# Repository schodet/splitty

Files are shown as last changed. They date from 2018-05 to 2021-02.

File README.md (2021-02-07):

Splitty
=======

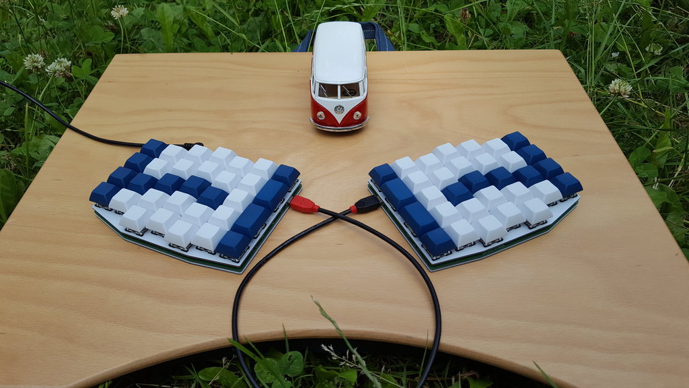
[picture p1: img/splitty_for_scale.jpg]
Splitty


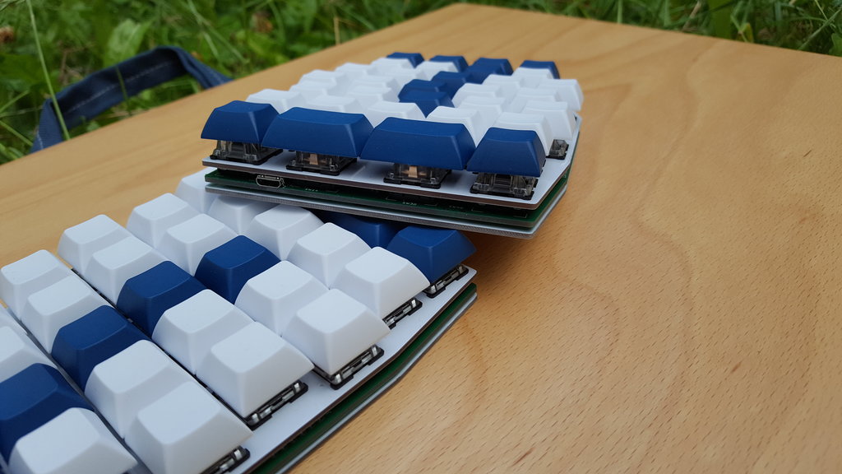
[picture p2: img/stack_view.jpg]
Splitty Stack


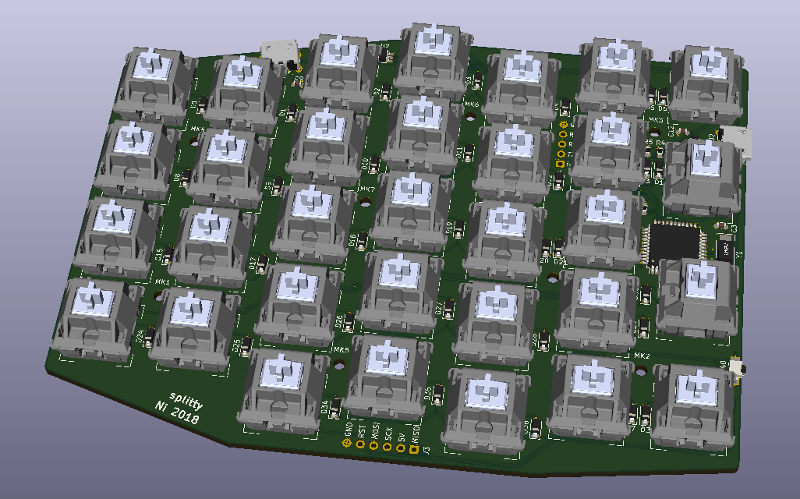
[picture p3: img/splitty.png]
Splitty PCB


[More pictures](gallery.md)

This is a split ergonomic keyboard based on the Ergodox layout without the
thumb cluster. It uses 32 keys per sides with Cherry MX compatibles switches,
thirty 1u and two vertical 1.5u caps.

The controller is integrated in order to make the keyboard as slim as
possible.

It connects to the computer using a micro-B USB. Both sides are connected
together also using micro-B USB. Any connection mistake should not break
anything and the keyboard supports hot plugging.

BOM
---

All prices in euro.

Here is what is needed for one half, with references at Farnell and LCSC for
some parts.

| Quantity | Designator | Description | Farnell | Price | Total | LCSC | Price  | Total |
| ---: | --- | --- | ---: | ----: | ----: | ---: | -----: | ----: |
| 32 | SW0-38 | Cherry MX switches | | | | | | |
| 3 | C1, C11, C12 | Capacitor 0603 1μF >6V X7R | 2346895 | 0.055 | 0.165 |  C93816 | 0.0172 | 0.052 |
| 2 | C3, C4 | Capacitor 0603 22pF >6V C0G/NP0 | xxxxxxx | xxxxx | xxxxx | C106245 | 0.0084 | 0.017 |
| 6 | C5-10 | Capacitor 0603 100nF >6V X7R | 2320803 | 0.037 | 0.222 | C187860 | 0.0231 | 0.139 |
| 32 | D0-38 | Diode SOD-123 | 2760402 | 0.079 | 2.528 |  C83528 | 0.0091 | 0.291 |
| 2 | J1,J2 | Connector USB Micro-B Würth 629105150521 | 2470822 | 1.360 | 2.720 | | | |
| 2 | R1, R2 | Resistor 0603 22Ω | 9331891 | 0.002 | 0.004 | | | |
| 3 | R3, R4, R5 | Resistor 0603 10kΩ | xxxxxxx | xxxxx | xxxxx | | | |
| 1 | SW40 | Tactile Switches Omron B3U-3000P-B | 1333656 | 0.420 | 0.420 | | | |
| 1 | U1 | ATmega32U4-AU | 2443182 | 3.570 | 3.570 |  C44854 | 3.1513 | 3.151 |
| 2 | U2, U3 | ST USBLC6-2SC6 | 1269406 | 0.313 | 0.626 | C7519 | 0.1456 | 0.291 |
| 1 | Y1 | Crystal Abracon ABM3 16MHz | 1611806 | 0.660 | 0.660 | | | |
| 8 | | M2 screw, 6mm | 1420386 | 0.012 | 0.094 | | | |
| 16 | | M2 nuts | 1419445 | 0.009 | 0.150 | | | |
| | | | | Total | 11.19 | | | |
| | | | | x2 | 22.38 | | | |

Boards were ordered at JLCPCB, you can ask for delivery of JLCPCB and LCSC
orders in the same package.

| Description | JLCPCB by | Price | Unit  | JLCPCB by | Price | Unit  |
| --- | --- | ----- | ----- | --- | ----- | ----- |
| Printed Circuit Board (green) | 5 | 11.25 | 2.250 | 10 | 15.20 | 1.520 |
| Front Plate (white) | 5 | 18.55 | 3.710 | 10 | 22.49 | 2.249 |
| Back Plate (white) | 5 | 18.55 | 3.710 | 10 | 22.49 | 2.249 |

My actual orders
----------------

Cool Jazz (AliExpress):

 - 92 Gateron MX brown switches: 21.93 €
 - Ergodox PBT blank keycaps (60 1u, 16 1.5u, 4 2u): 23.12 €
 - Total: 45.05 €

Farnell:

 - 4 connector USB: 5.44 €
 - 2 quartz: 1.32 €
 - 100 screws: 1.17 €
 - 100 nuts: 0.94 €
 - Shipping: 6.90 €
 - Taxes: 3.16 €
 - Total: 18.93 €

JLCPCB + LCSC:

 - 5 PCB: 11.25 €
 - 5 Front Plate: 18.55 €
 - 5 Back Plate: 18.55 €
 - Shipping (JLCPCB, DHL): 5.03 €
 - 10 ST USBLC6: 0.72 €
 - 4 ATmega32U4: 12.59 €
 - 140 diodes: 1.27 €
 - 50 1uF capacitors: 0.86 €
 - Shipping (LCSC): 0.17 €
 - Taxes + DHL tip(!): 27 €
 - Total: 95.99 €

Personal stock:
 - Some resistors and capacitors.

I have enough components for two keyboards except USB connectors, quartz
(forgotten in Farnell order), switches and caps (they will probably be
different), and an extra set of boards.

Grand total: 159.97 €

Grand total (for one keyboard): 111.98 €

Slim stack
----------

A special attachment is used to make sure the stack is as slim as possible:

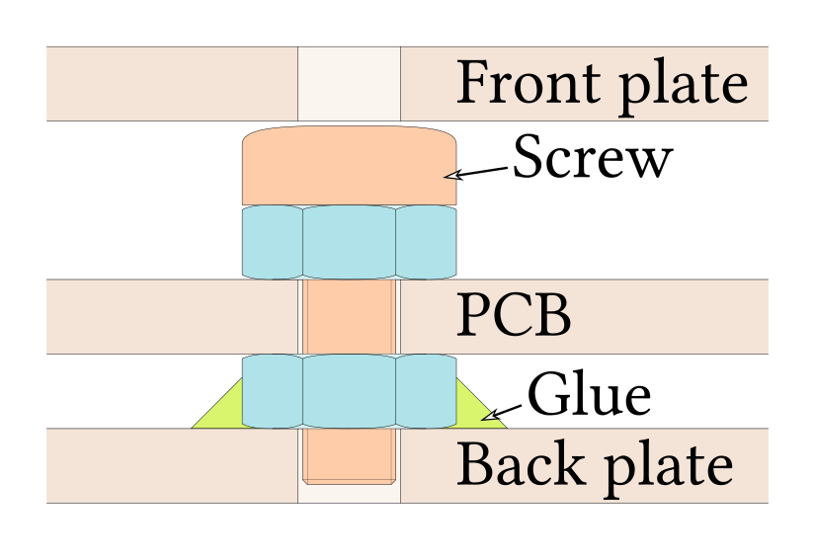
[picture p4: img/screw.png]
Screw attachment


Assembly and more
-----------------

See the [build log](build.md) and the [FAQ](faq.md).

License
-------

Copyright (C) 2018 Nicolas Schodet

Permission is hereby granted, free of charge, to any person obtaining a copy
of this software and associated documentation files (the "Software"), to deal
in the Software without restriction, including without limitation the rights
to use, copy, modify, merge, publish, distribute, sublicense, and/or sell
copies of the Software, and to permit persons to whom the Software is
furnished to do so, subject to the following conditions:

The above copyright notice and this permission notice shall be included in all
copies or substantial portions of the Software.

THE SOFTWARE IS PROVIDED "AS IS", WITHOUT WARRANTY OF ANY KIND, EXPRESS OR
IMPLIED, INCLUDING BUT NOT LIMITED TO THE WARRANTIES OF MERCHANTABILITY,
FITNESS FOR A PARTICULAR PURPOSE AND NONINFRINGEMENT. IN NO EVENT SHALL THE
AUTHORS OR COPYRIGHT HOLDERS BE LIABLE FOR ANY CLAIM, DAMAGES OR OTHER
LIABILITY, WHETHER IN AN ACTION OF CONTRACT, TORT OR OTHERWISE, ARISING FROM,
OUT OF OR IN CONNECTION WITH THE SOFTWARE OR THE USE OR OTHER DEALINGS IN THE
SOFTWARE.

The splitty symbol and footprint libraries use the same license.

Artwork on the back plate was made from "Van Volkswagen Vintage Old Car
Transporter Vw" under Creative Commons Zero - CC0.

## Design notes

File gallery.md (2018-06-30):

Splitty gallery
===============

Splitty for scale

Stack view

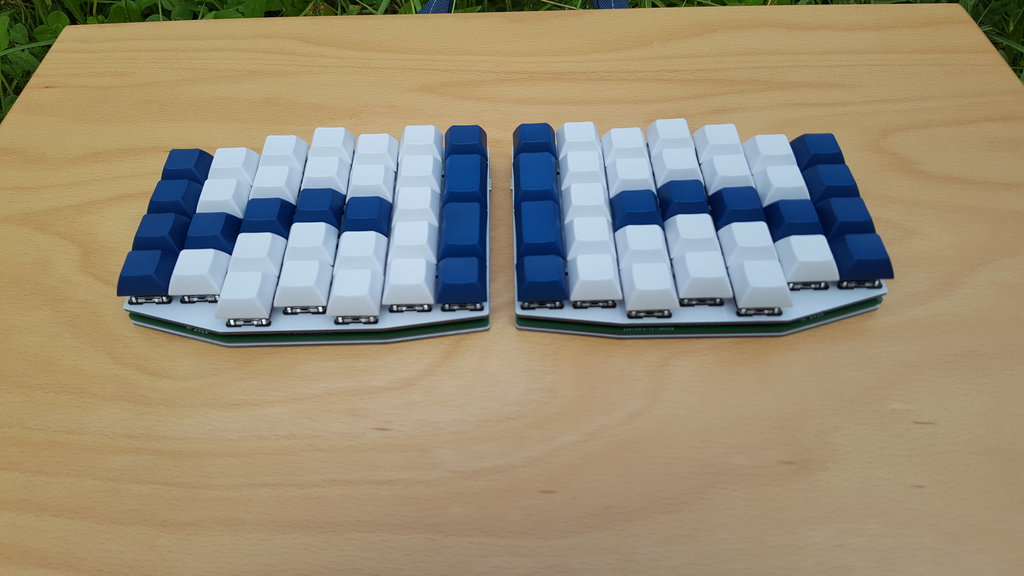
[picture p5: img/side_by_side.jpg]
Side by side


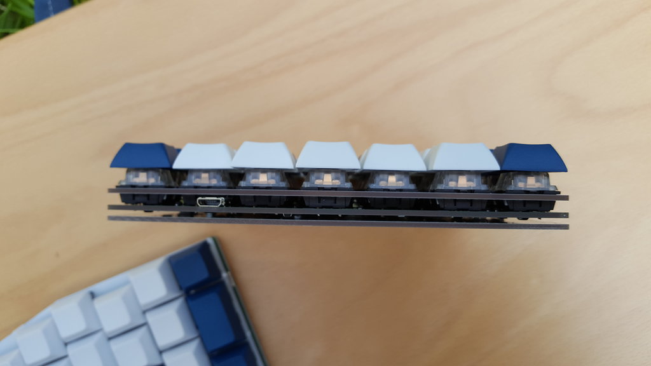
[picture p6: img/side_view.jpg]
Side view


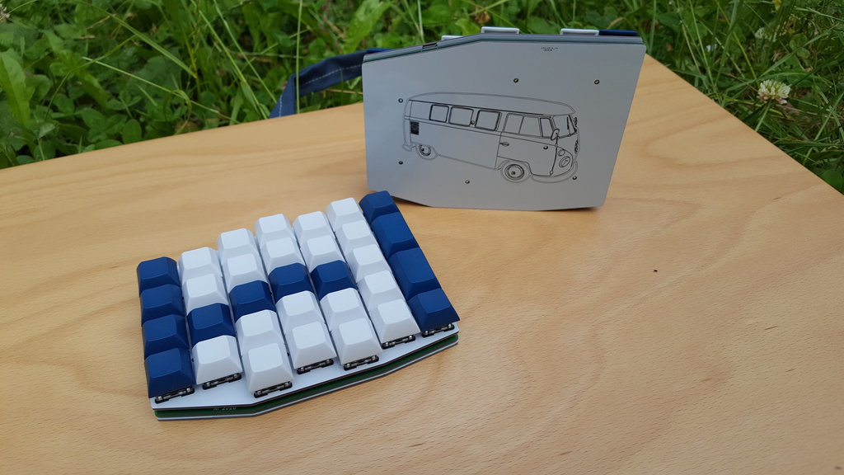
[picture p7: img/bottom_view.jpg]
Bottom view


PCB render

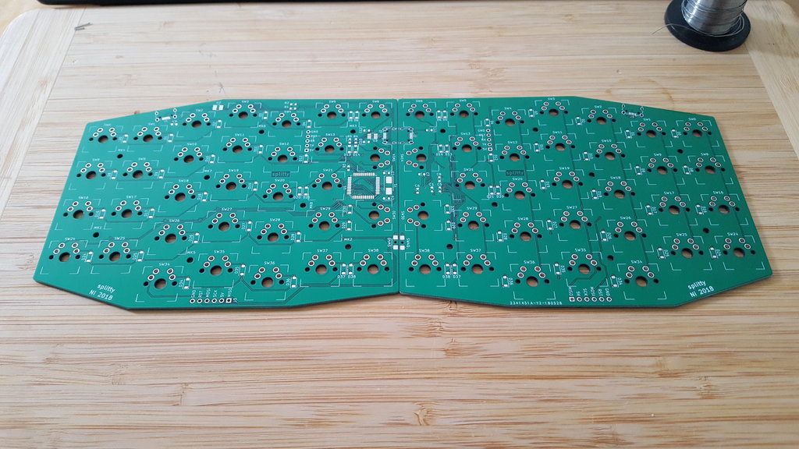
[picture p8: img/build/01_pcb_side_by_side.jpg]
PCB side by side


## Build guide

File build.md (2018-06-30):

Build log
=========

Here are my tools used to solder the splitty:

- a simple soldering iron (with a quite large tip),
- solder (make sure the iron temperature matches the solder),
- a metallic sponge,
- solder wick (for fast SMD soldering),
- tweezers.

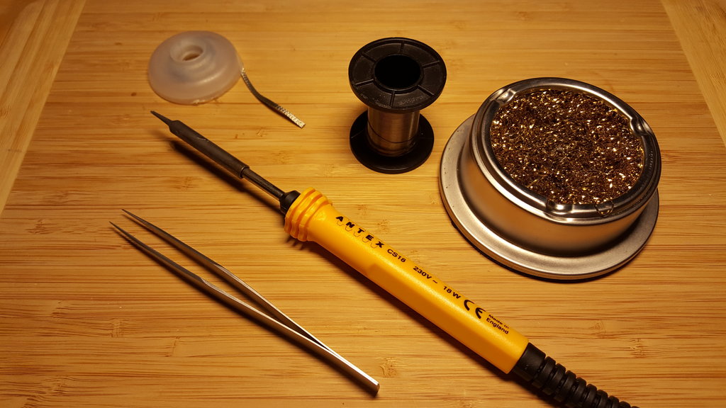
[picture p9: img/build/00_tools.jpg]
Tools


Also not shown on the picture:

- a small screwdriver,
- a 4 mm wrench or pliers,
- a flush cutter,
- a conductivity tester,
- a magnifier,
- glue (cyanoacrylate).

OK, let’s start.

The PCB is the same for both halves, one will have components on top and the
other on the bottom face.

Some components can be soldered on any face:

- the switches of course,
- diodes can be soldered on any face, choose your side,
- connectors and reset switch are supposed to be soldered on the top face,
- only one of C11 or C12 need to be soldered, choose one.

Lay down PCBs side by side to avoid silly mistakes:

PCB side by side

First components to solder are the diodes, check the polarity, the thin line
on the component corresponds to the cathode and must be oriented on the side
with the longer line on the silkscreen.

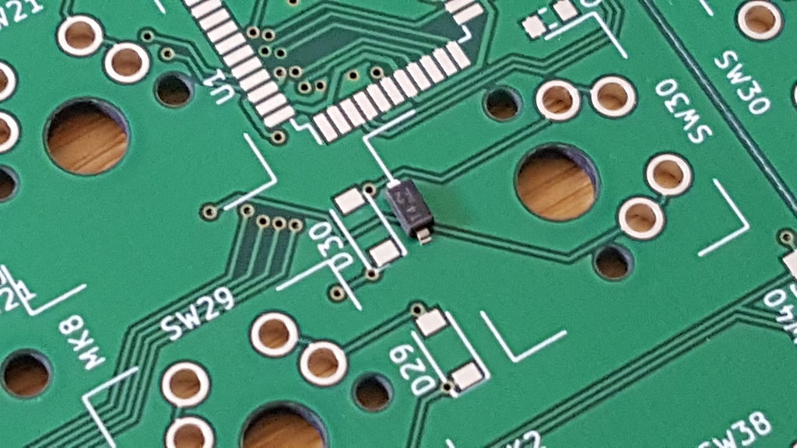
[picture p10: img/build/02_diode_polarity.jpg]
Diode polarity


The technique to solder small components is always the same, apply some solder
on one pad on the PCB, then press the component against the board and heat its
leg and your solder pad. The component will sink into the solder. Then, apply
solder to the other side while heating both the pad and the leg.

If one side is connected to a copper plane, choose this pad as the first one.
If you don’t, there is a risk that the first pad solder will melt while you
try to heat the pad connected to the plane.

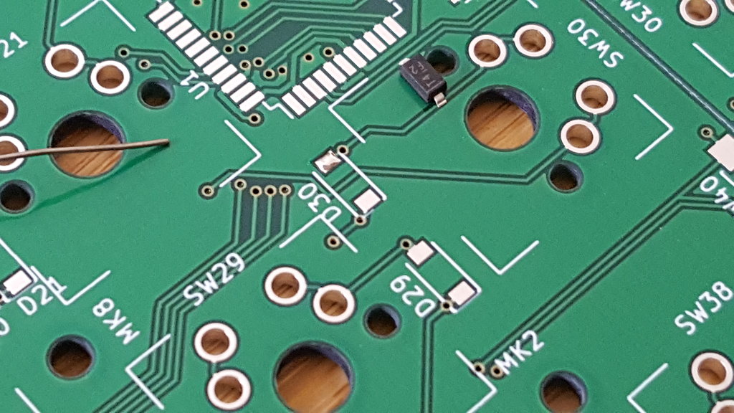
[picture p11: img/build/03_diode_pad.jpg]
Put solder on the first pad

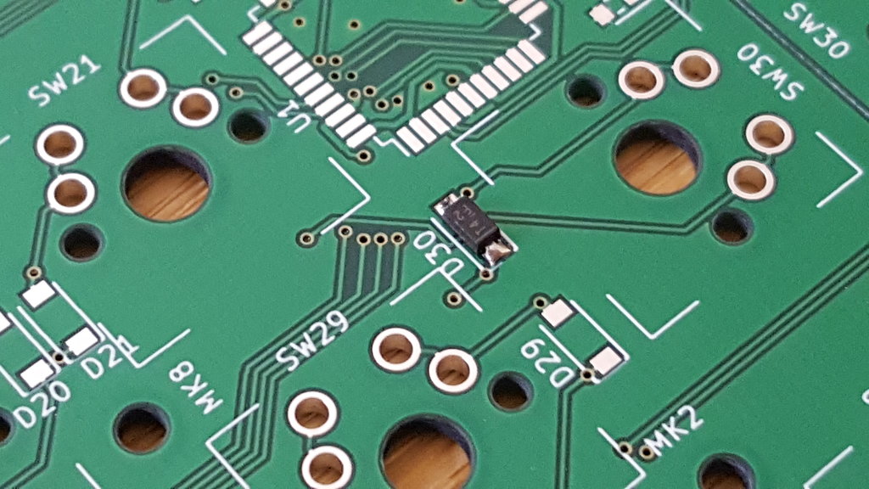
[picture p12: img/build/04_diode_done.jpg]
Soldered diode


Next component to solder is the micro USB socket as this is the trickiest part
to solder.

Start with the same technique used for the diodes. Apply solder on one pad,
choose the pad connected to the ground plane. Push the connector into place
while heating its leg and the pad and check the alignment is correct.

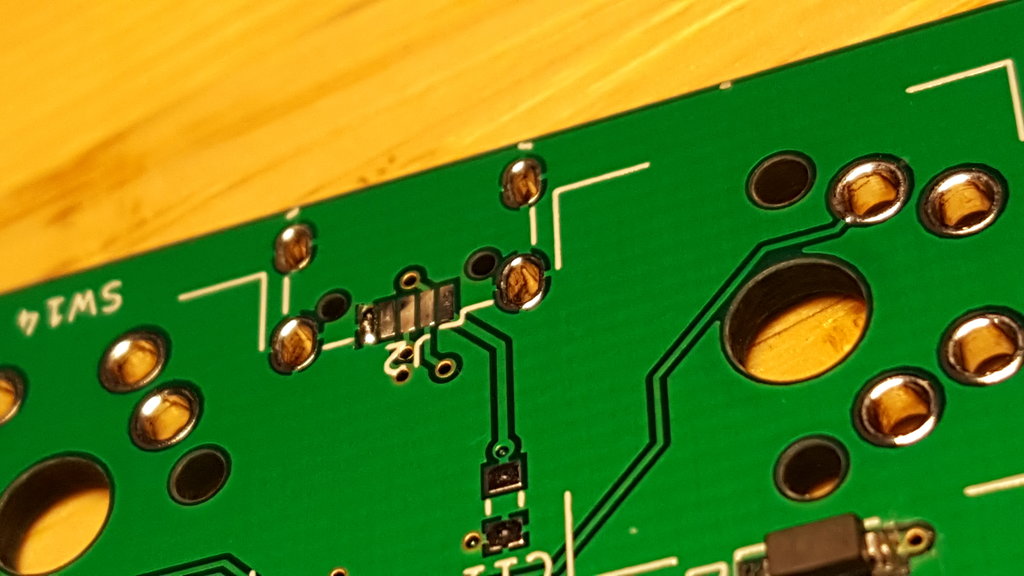
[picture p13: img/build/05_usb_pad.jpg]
The first USB pad


Then I use a surprising technique which works really well for components with
small pitch: apply solder to all pads and legs, with proper heating to both
the pads and the legs as always. All the pads… as the same time… there will be
shorts.

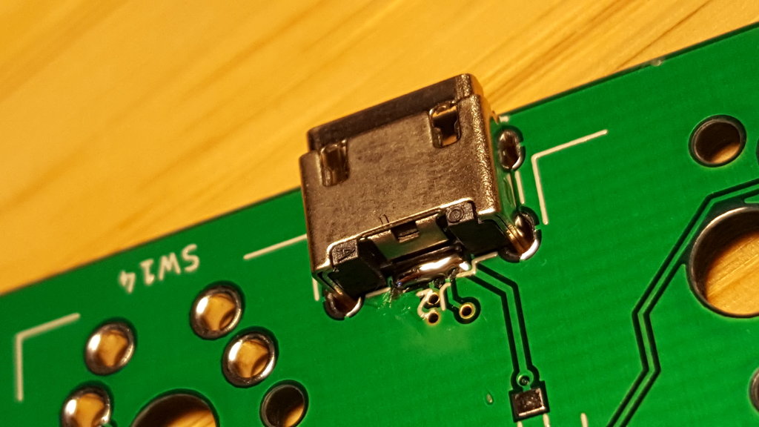
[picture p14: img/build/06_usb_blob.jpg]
Do not fear the solder blob


Now, put the solder wick above the contacts, apply a little drop of solder on
the tip of your iron to improve heat transfer, then press it firmly against
the wick for two seconds. Most solder will be sucked by the solder wick and
only a sufficient amount on solder will stay, removing any shorts while still
ensuring a good contact.

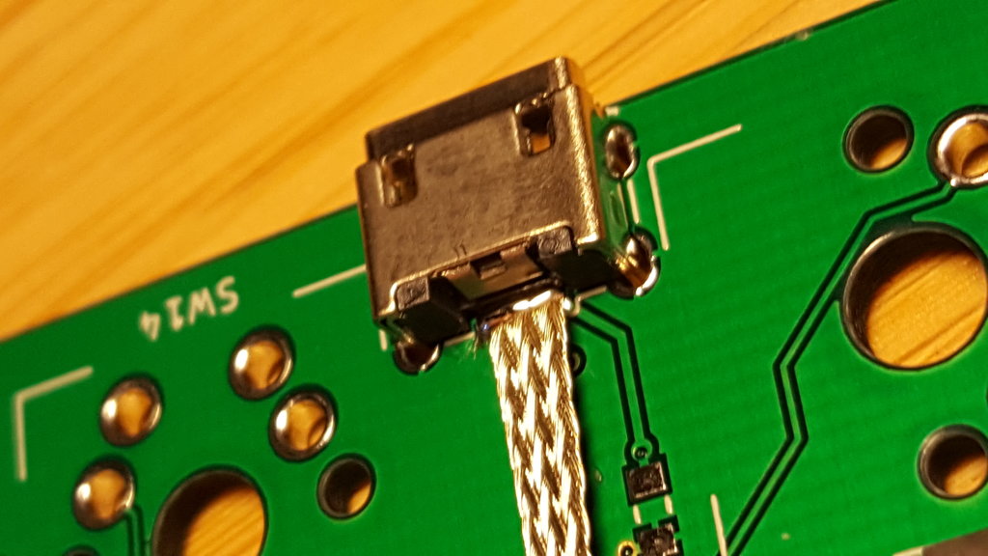
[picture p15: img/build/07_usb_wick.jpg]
This technique really sucks!


Now solder the large legs to ensure good mechanical support.

Test your connections, this is easy with this kind of cable, you can even
apply some force on the connector and see if the connection is rock solid:

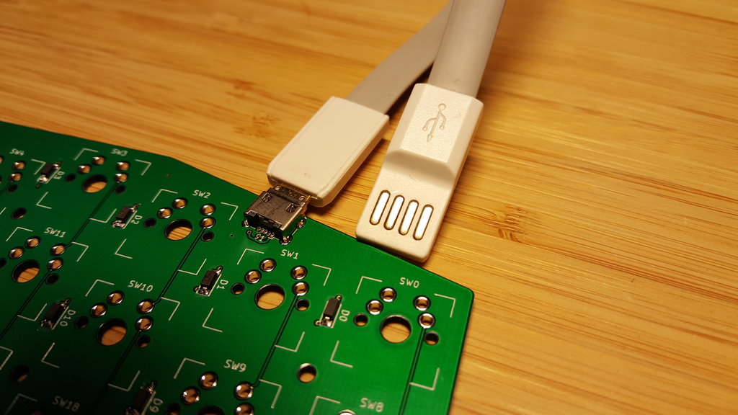
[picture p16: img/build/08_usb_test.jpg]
Nude USB contacts


Soldering the rest of the components is a piece of cake, but keep things
organized:

(TODO: make a video of how easy it is to solder a ATMEGA32u4).

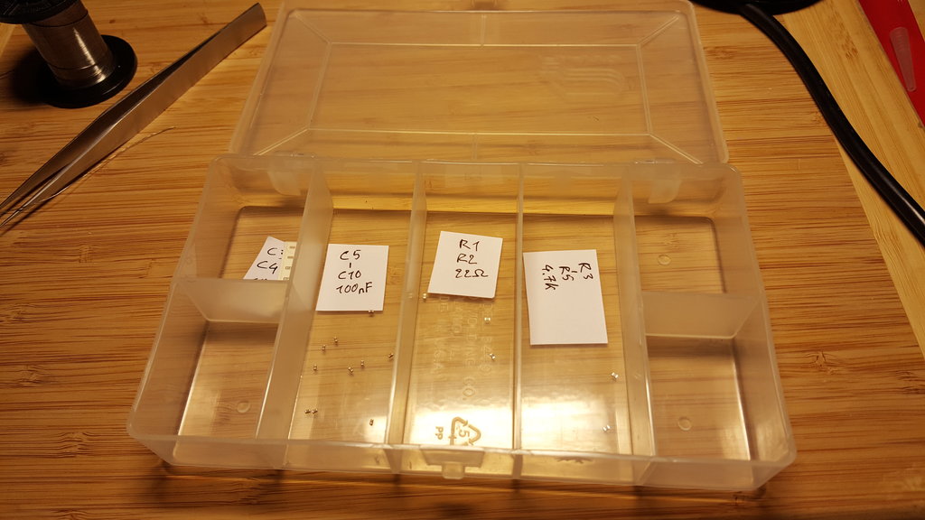
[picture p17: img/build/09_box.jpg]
When the box is empty, you’re done


The splitty does not use spacers, and you need to prepare screws now before
the front plate is attached.

Here is a schematic of the attachment:

Screw attachment

Before the switches and therefore the front plate are mounted, you need to
install the screws and the first nuts. A nut is temporary used on the other
side so that the screw does not fall during the preparation.

Now it is time to test *every* connections. Repairing a connection (especially
on the left hand half) will be much harder once the front plate is installed!

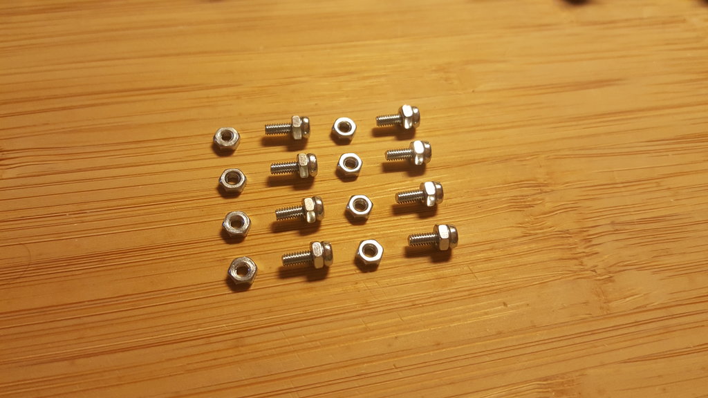
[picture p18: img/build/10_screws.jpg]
The height screws and their companions


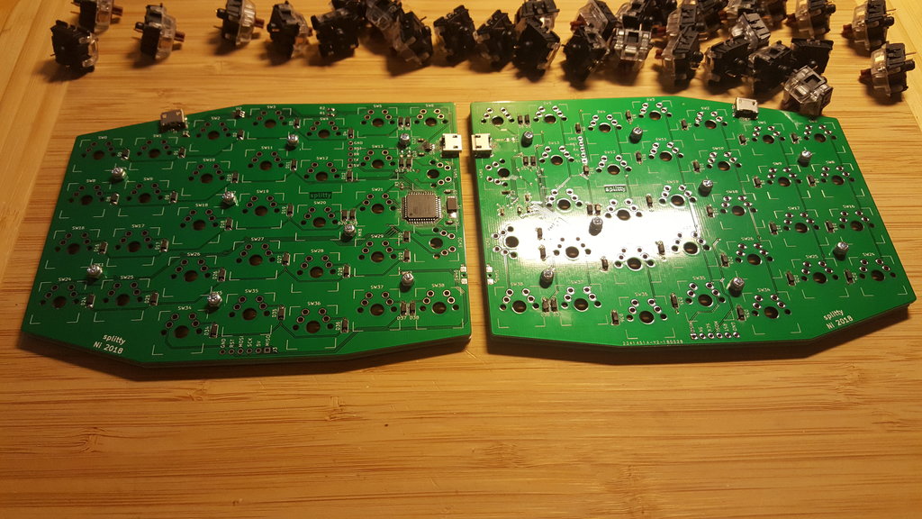
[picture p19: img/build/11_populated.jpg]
Ready to mount the switches


First start with the corner switches so that the front plate is leveled.

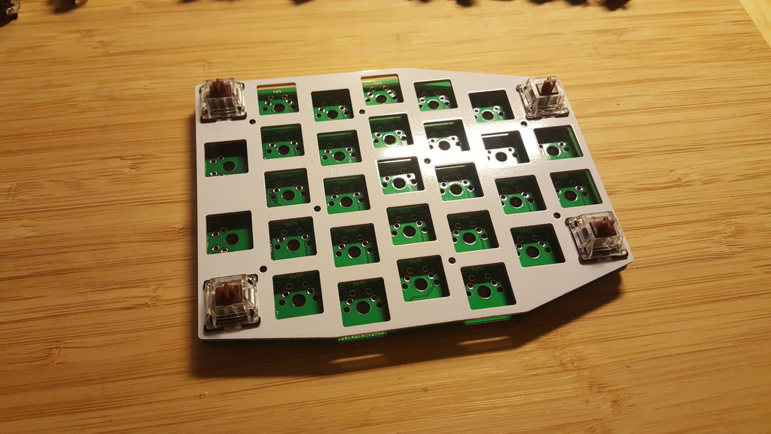
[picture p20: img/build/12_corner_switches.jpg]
Corner switches


Then proceed with the other switches.

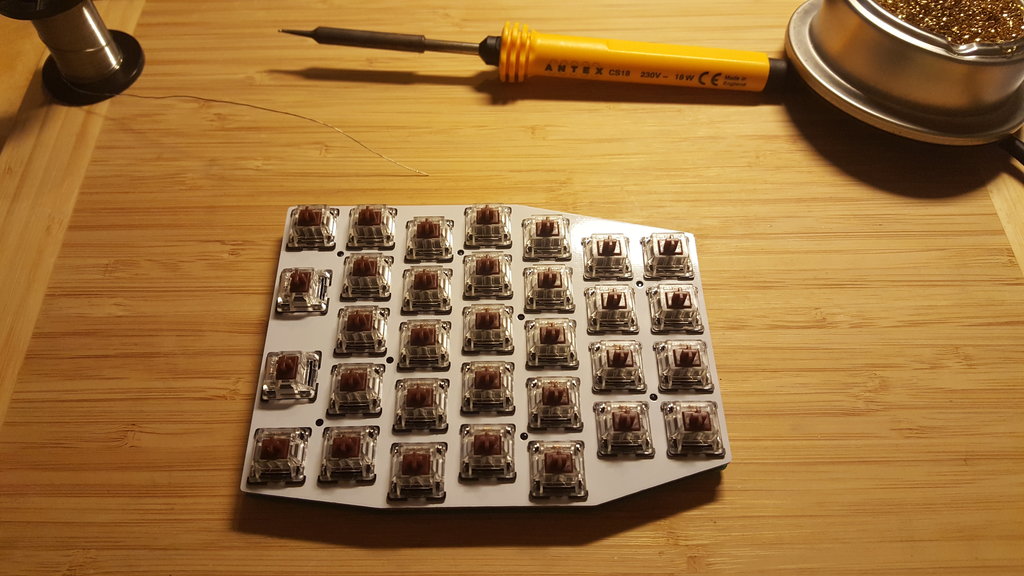
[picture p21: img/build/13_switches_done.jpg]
Now this really looks like a keyboard!


I started with the right side so a mistake can be fix more easily.

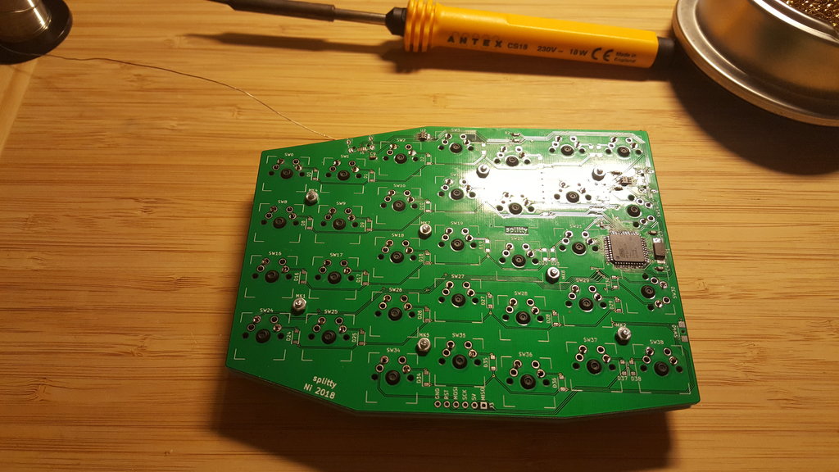
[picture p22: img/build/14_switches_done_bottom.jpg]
Under the switches


To glue the nuts to the bottom plate, use a screw to hold the nut in place.

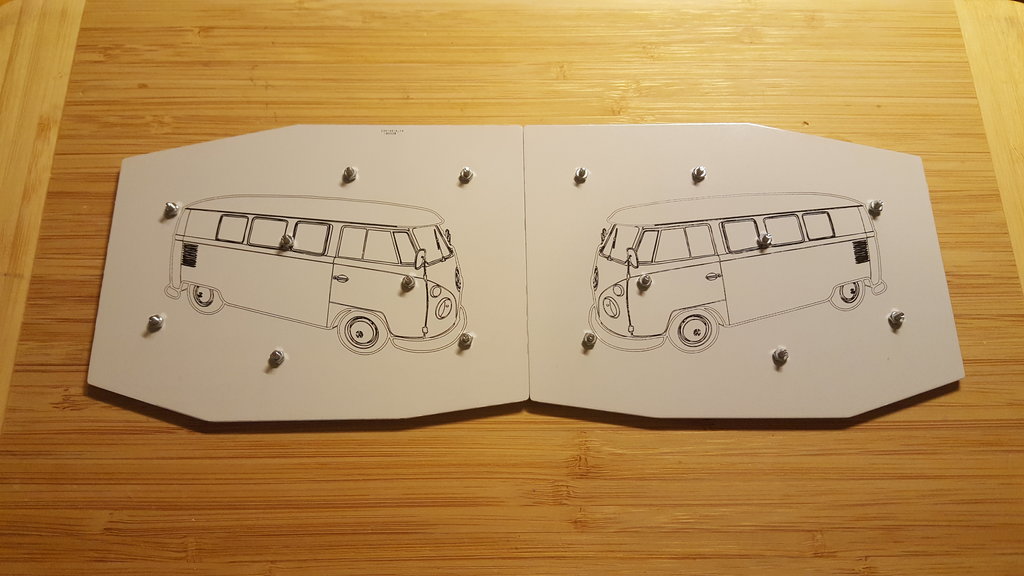
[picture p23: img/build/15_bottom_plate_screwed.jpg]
Bottom plate screwed


Apply glue around every nuts and remove the screw before the glue has
completely dried.

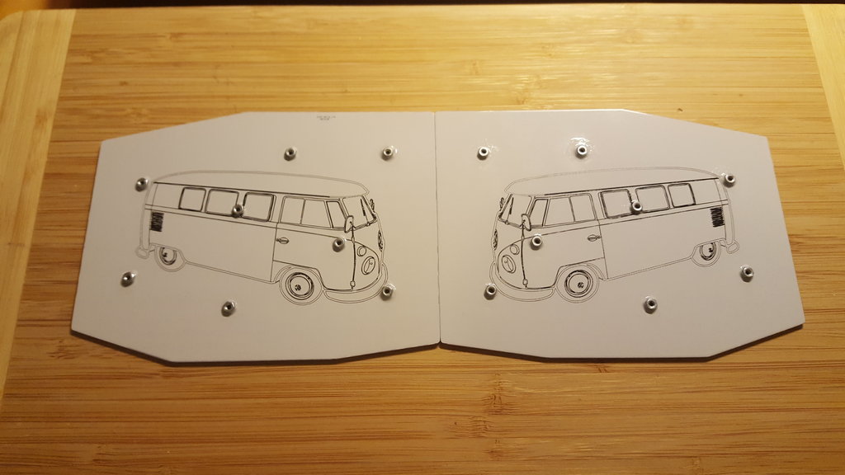
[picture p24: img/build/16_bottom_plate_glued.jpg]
Same thing, but without the screws


Depending on your switches and nuts, you may need to cut a little bit of the
switches legs. Another solution is to add enough washers so that is not
needed.

For the final assembly, you can not screw every screw one after the other, you
need to turn one turn on every screws, then repeat until every screws are
tighten.

Well done:

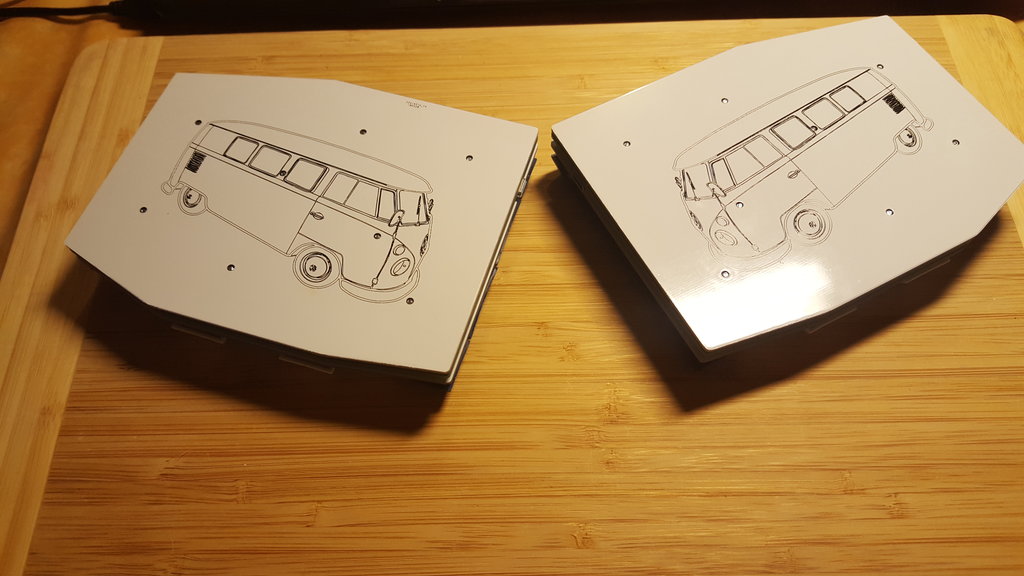
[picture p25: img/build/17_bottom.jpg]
Bottom


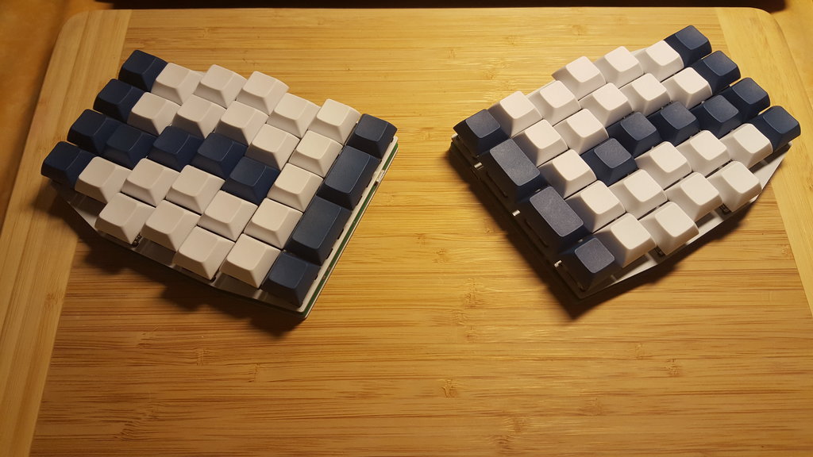
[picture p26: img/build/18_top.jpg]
Top


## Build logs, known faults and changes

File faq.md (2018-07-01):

FAQ
===

Why is the inner index column staggered up?
-------------------------------------------

Because I find it more comfortable to extend the index to the side and up
rather than straight to the side.

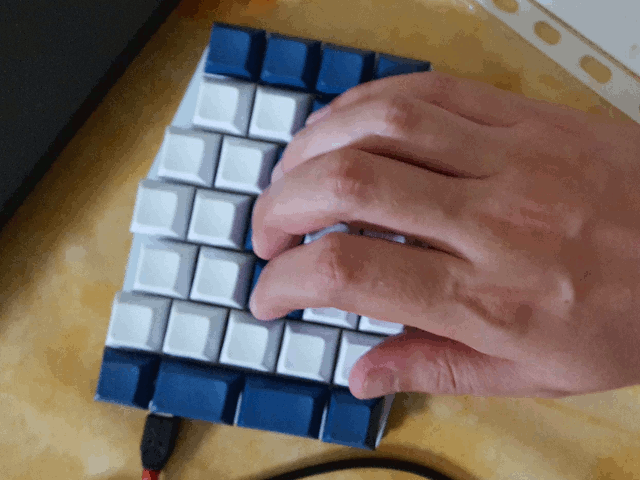
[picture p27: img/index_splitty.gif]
The splitty way


A right hand on a left splitty half to simulate the other stagger:

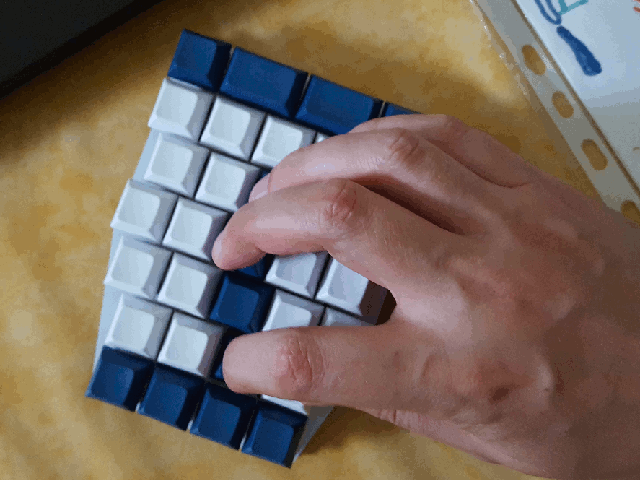
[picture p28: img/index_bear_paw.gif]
The other way


I am not alone, the same arrangement is used on the [mitosis][] for example.

It is also the case of a strange keyboard that a lot of people uses, as the
arm come from the side, the inner row is actually shifted up:

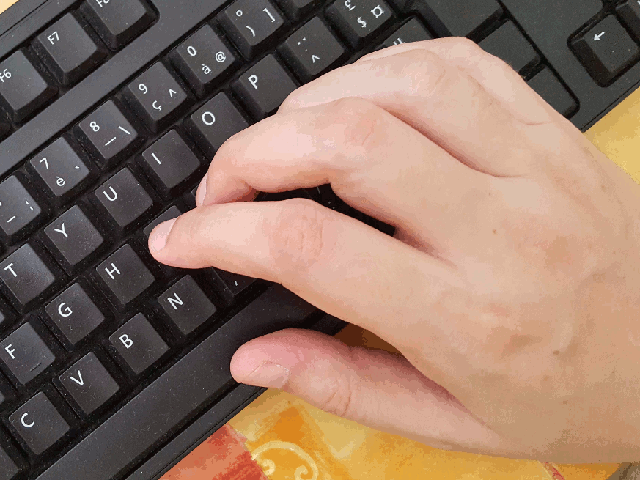
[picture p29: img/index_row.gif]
The strange row staggered keyboard


[mitosys]: https://www.reddit.com/r/MechanicalKeyboards/comments/66588f/wireless_split_qmk_mitosis/

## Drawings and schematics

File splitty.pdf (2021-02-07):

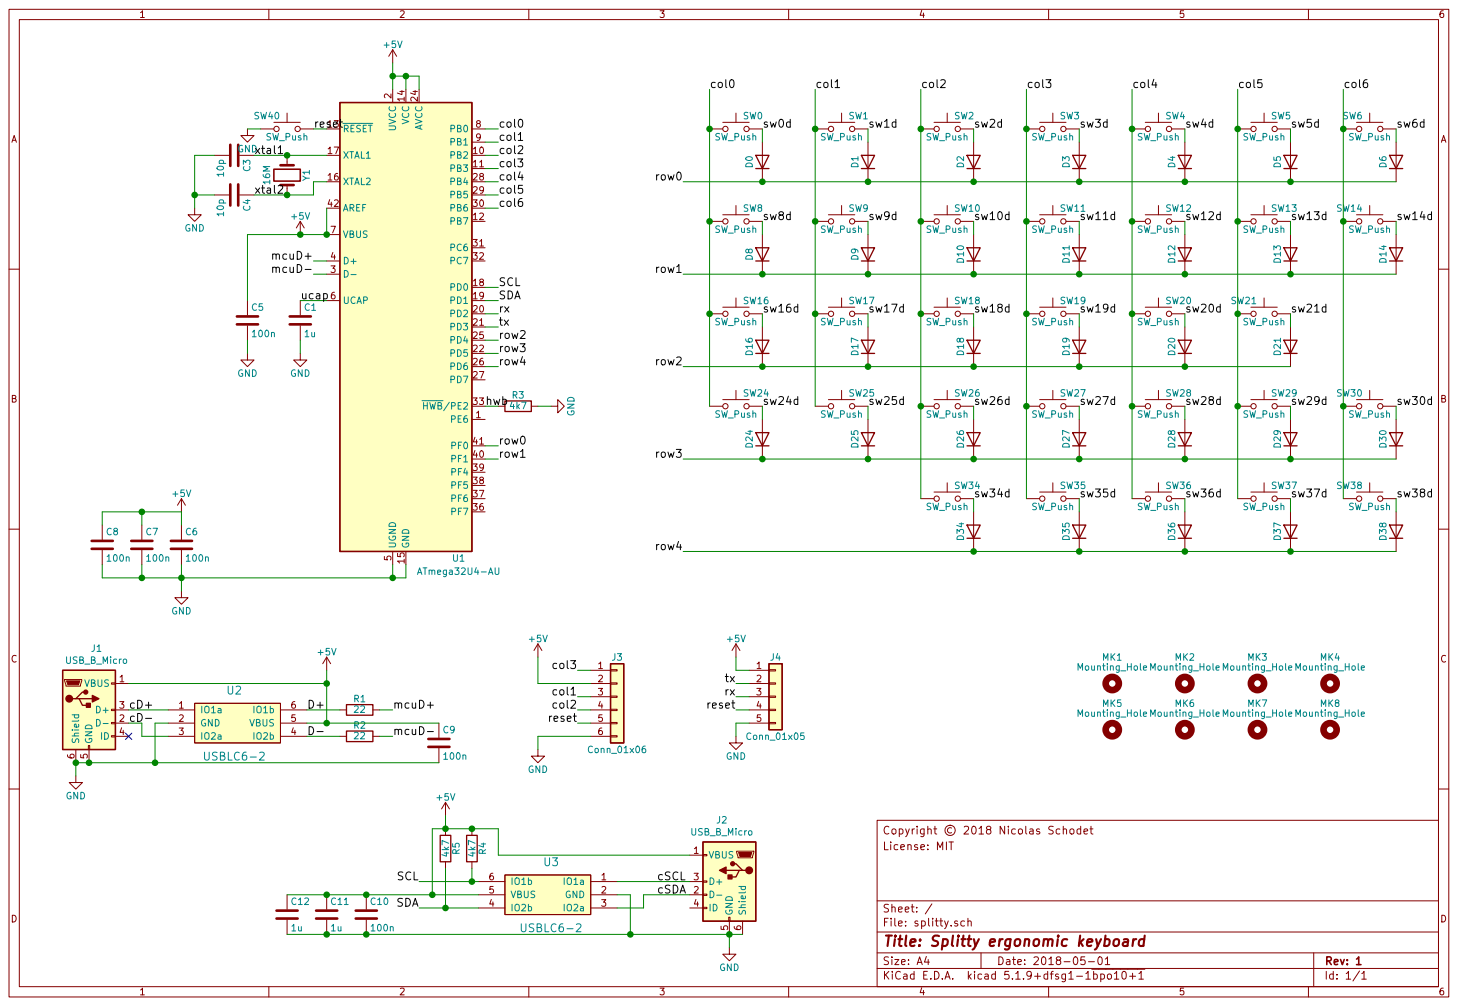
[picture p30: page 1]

2 PD2 20 PD3 21 PD5 22 AVCC 24 PD4 25 PD6 26 PD7 27 PB4 28 PB5 29 D- 3 PB6 30 PC6 31 PC7 32 HWB/PE2 33 PF7 36 PF6 37 PF5 38 PF4 39 D+ 4 PF1 40 PF0 41 AREF 42 UGND

5 UCAP 6 VBUS 7 PB0 8 PB1 9 U1 ATmega32U4-AU GND

SW8 SW_PushD8 SW16 SW_PushD16 SW24 SW_Push | SW2 SW_Push | SW12 SW_Push SW1 SW_PushD1 SW9 SW_PushD9 SW17 SW_PushD17 SW25 SW_PushD25

sw17d SCL

File: splitty.sch Sheet: / License: MIT Copyright © 2018 Nicolas Schodet

Id: 1/1 Title: Splitty ergonomic keyboard

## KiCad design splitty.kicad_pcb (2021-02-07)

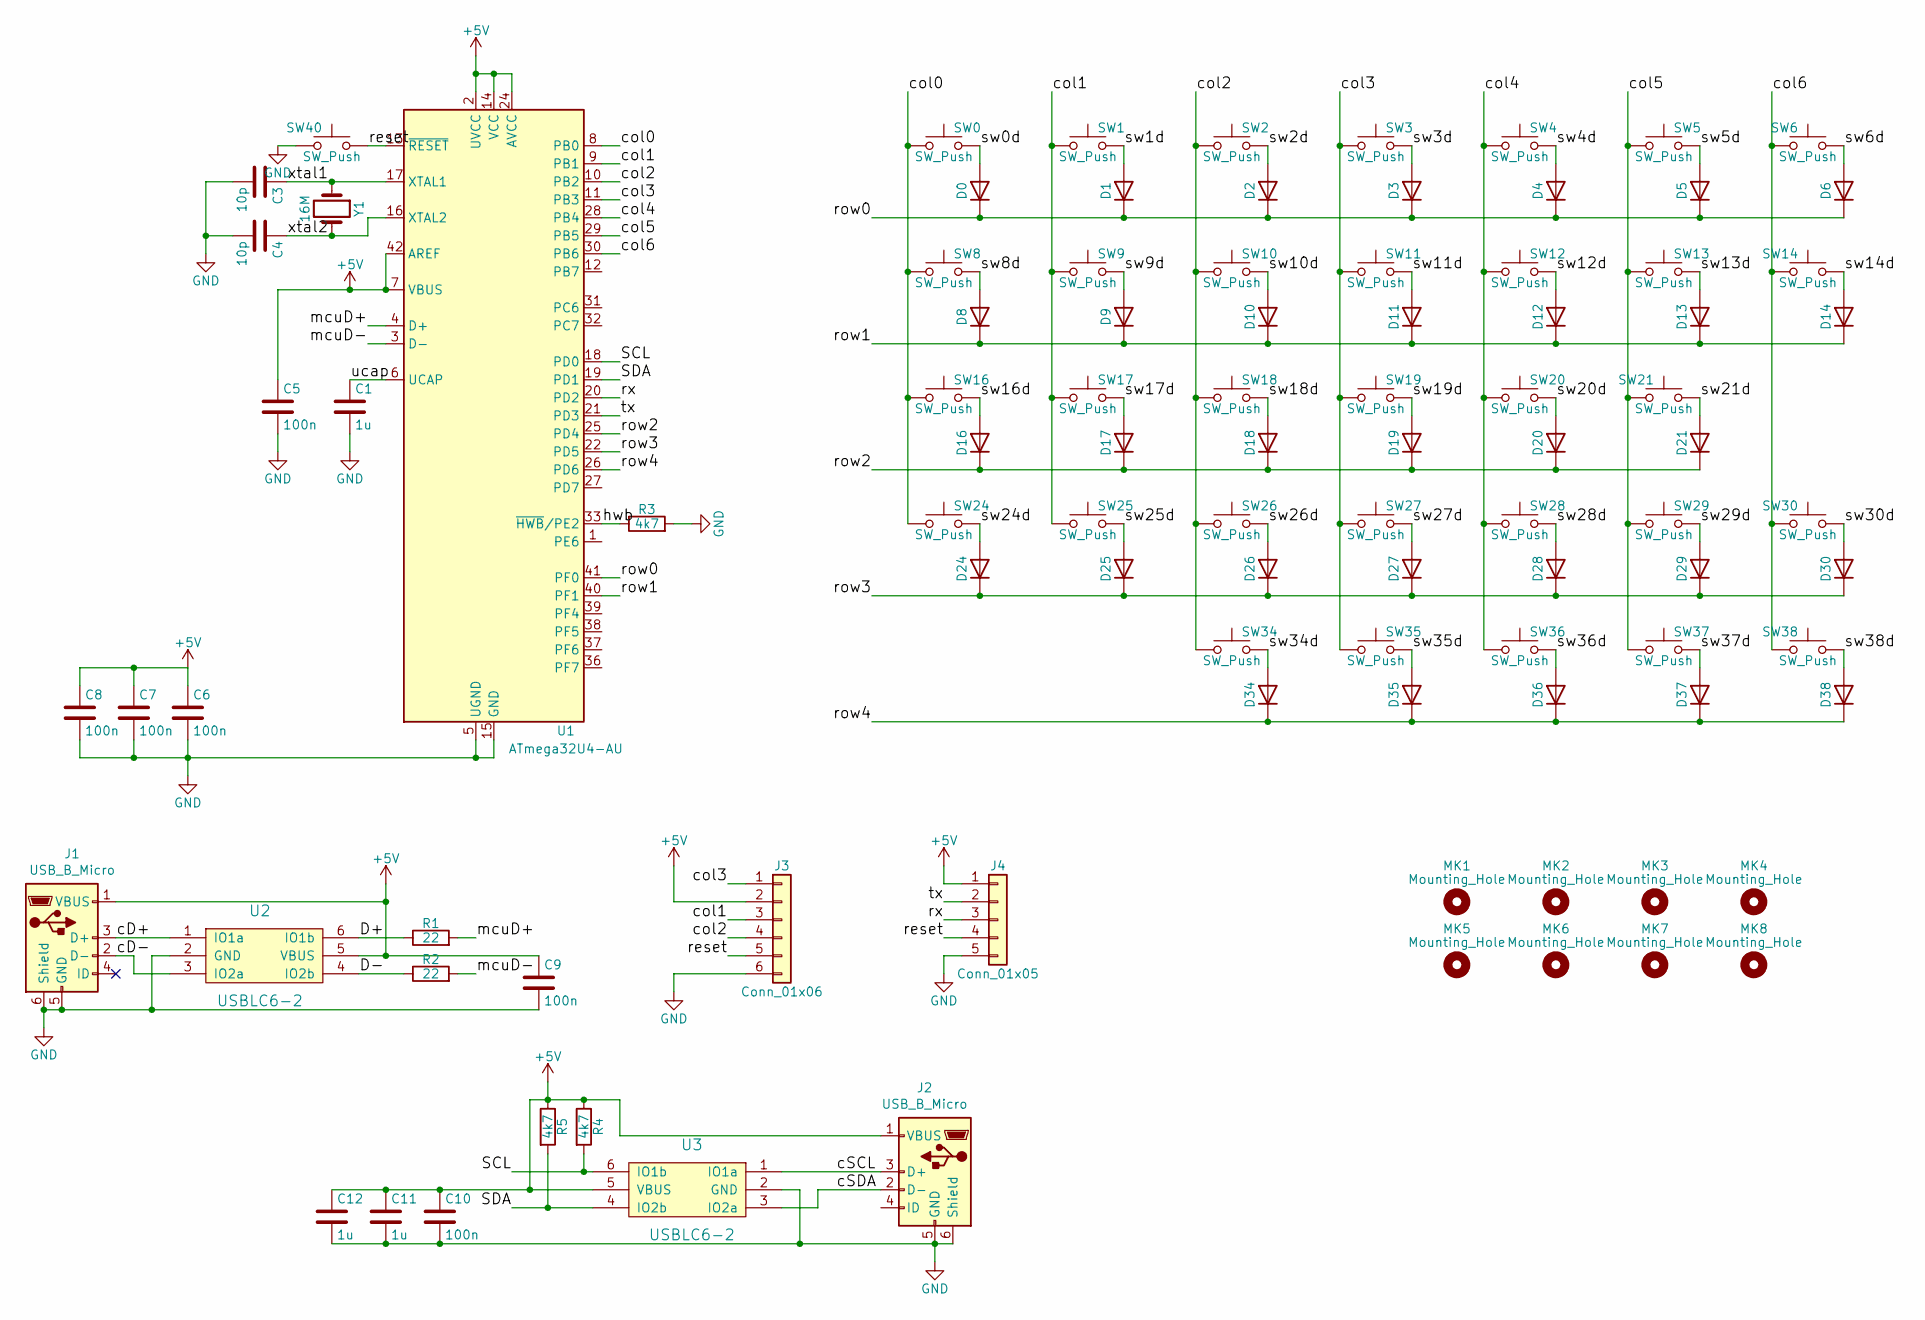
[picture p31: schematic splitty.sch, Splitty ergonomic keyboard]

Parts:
C1, C11, C12: 1u; C_0603_1608Metric_Pad1.05x0.95mm_HandSolder
C3, C4: 10p; C_0603_1608Metric_Pad1.05x0.95mm_HandSolder
C5, C6, C7, C8, C9, C10: 100n; C_0603_1608Metric_Pad1.05x0.95mm_HandSolder
D0, D1, D2, D3, D4, D5, D6, D8, D9, D10, D11, D12, D13, D14, D16, D17, D18, D19, D20, D21, D24, D25, D26, D27, D28, D29, D30, D34, D35, D36, D37, D38: D; D_SOD-123_BothSides
J1, J2: USB_B_Micro; USB_Micro-B_Wuerth_629105150521_BothSides
J3: Conn_01x06; PinHeader_1x06_P2.54mm_Vertical
J4: Conn_01x05; PinHeader_1x05_P2.54mm_Vertical
MK1, MK2, MK3, MK4, MK5, MK6, MK7, MK8: Mounting_Hole; MountingHole_2.2mm_M2
R1, R2: 22; R_0603_1608Metric_Pad1.05x0.95mm_HandSolder
R3, R4, R5: 4k7; R_0603_1608Metric_Pad1.05x0.95mm_HandSolder
SW0, SW1, SW2, SW3, SW4, SW5, SW6, SW8, SW9, SW10, SW11, SW12, SW13, SW16, SW17, SW18, SW19, SW20, SW21, SW24, SW25, SW26, SW27, SW28, SW29, SW34, SW35, SW36, SW37, SW38: SW_Push; SW_Cherry_MX1A_1.00u_PCB_BothSides
SW14, SW30: SW_Push; SW_Cherry_MX1A_1.50u_PCB_BothSides
SW40: SW_Push; Tact_Switch_Side_Boss_B3U-3000P-B_BothSides_HandSolder
U1: ATmega32U4-AU; TQFP-44_10x10mm_P0.8mm
U2, U3: USBLC6-2; SOT-23-6_Handsoldering
Y1: 16M; Crystal_SMD_Abracon_ABM3-2Pin_5.0x3.2mm_HandSoldering

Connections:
+5V: C5.1, C6.1, C7.1, C8.1, C9.1, C10.1, C11.1, C12.1, J1.1 (VBUS), J2.1 (VBUS), J3.2, J4.1, R4.1, R5.1, U1.2 (UVCC), U1.7 (VBUS), U1.14 (VCC), U1.24 (AVCC), U1.34 (VCC), U1.42 (AREF), U1.44 (AVCC), U2.5 (VBUS), U3.5 (VBUS)
/D+: R1.1, U2.6 (IO1b)
/D-: R2.1, U2.4 (IO2b)
/SCL: R4.2, U1.18 (PD0), U3.6 (IO1b)
/SDA: R5.2, U1.19 (PD1), U3.4 (IO2b)
/cD+: J1.3 (D+), U2.1 (IO1a)
/cD-: J1.2 (D-), U2.3 (IO2a)
/cSCL: J2.3 (D+), U3.1 (IO1a)
/cSDA: J2.2 (D-), U3.3 (IO2a)
/col0: SW0.1, SW8.1, SW16.1, SW24.1, U1.8 (PB0)
/col1: J3.3, SW1.1, SW9.1, SW17.1, SW25.1, U1.9 (PB1)
/col2: J3.4, SW2.1, SW10.1, SW18.1, SW26.1, SW34.1, U1.10 (PB2)
/col3: J3.1, SW3.1, SW11.1, SW19.1, SW27.1, SW35.1, U1.11 (PB3)
/col4: SW4.1, SW12.1, SW20.1, SW28.1, SW36.1, U1.28 (PB4)
/col5: SW5.1, SW13.1, SW21.2, SW29.1, SW37.1, U1.29 (PB5)
/col6: SW6.2, SW14.2, SW30.2, SW38.2, U1.30 (PB6)
/hwb: R3.1, U1.33 (~HWB~/PE2)
/mcuD+: R1.2, U1.4 (D+)
/mcuD-: R2.2, U1.3 (D-)
/reset: J3.5, J4.4, SW40.1, U1.13 (~RESET)
/row0: D0.1 (K), D1.1 (K), D2.1 (K), D3.1 (K), D4.1 (K), D5.1 (K), D6.1 (K), U1.41 (PF0)
/row1: D8.1 (K), D9.1 (K), D10.1 (K), D11.1 (K), D12.1 (K), D13.1 (K), D14.1 (K), U1.40 (PF1)
/row2: D16.1 (K), D17.1 (K), D18.1 (K), D19.1 (K), D20.1 (K), D21.1 (K), U1.25 (PD4)
/row3: D24.1 (K), D25.1 (K), D26.1 (K), D27.1 (K), D28.1 (K), D29.1 (K), D30.1 (K), U1.22 (PD5)
/row4: D34.1 (K), D35.1 (K), D36.1 (K), D37.1 (K), D38.1 (K), U1.26 (PD6)
/rx: J4.3, U1.20 (PD2)
/sw0d: D0.2 (A), SW0.2
/sw1d: D1.2 (A), SW1.2
/sw2d: D2.2 (A), SW2.2
/sw3d: D3.2 (A), SW3.2
/sw4d: D4.2 (A), SW4.2
/sw5d: D5.2 (A), SW5.2
/sw6d: D6.2 (A), SW6.1
/sw8d: D8.2 (A), SW8.2
/sw9d: D9.2 (A), SW9.2
/sw10d: D10.2 (A), SW10.2
/sw11d: D11.2 (A), SW11.2
/sw12d: D12.2 (A), SW12.2
/sw13d: D13.2 (A), SW13.2
/sw14d: D14.2 (A), SW14.1
/sw16d: D16.2 (A), SW16.2
/sw17d: D17.2 (A), SW17.2
/sw18d: D18.2 (A), SW18.2
/sw19d: D19.2 (A), SW19.2
/sw20d: D20.2 (A), SW20.2
/sw21d: D21.2 (A), SW21.1
/sw24d: D24.2 (A), SW24.2
/sw25d: D25.2 (A), SW25.2
/sw26d: D26.2 (A), SW26.2
/sw27d: D27.2 (A), SW27.2
/sw28d: D28.2 (A), SW28.2
/sw29d: D29.2 (A), SW29.2
/sw30d: D30.2 (A), SW30.1
/sw34d: D34.2 (A), SW34.2
/sw35d: D35.2 (A), SW35.2
/sw36d: D36.2 (A), SW36.2
/sw37d: D37.2 (A), SW37.2
/sw38d: D38.2 (A), SW38.1
/tx: J4.2, U1.21 (PD3)
/ucap: C1.1, U1.6 (UCAP)
/xtal1: C3.1, U1.17 (XTAL1), Y1.1
/xtal2: C4.1, U1.16 (XTAL2), Y1.2
GND: C1.2, C3.2, C4.2, C5.2, C6.2, C7.2, C8.2, C9.2, C10.2, C11.2, C12.2, J1.5 (GND), J1.6 (Shield), J2.5 (GND), J2.6 (Shield), J3.6, J4.5, R3.2, SW40.2, U1.5 (UGND), U1.15 (GND), U1.23 (GND), U1.35 (GND), U1.43 (GND), U2.2 (GND), U3.2 (GND)

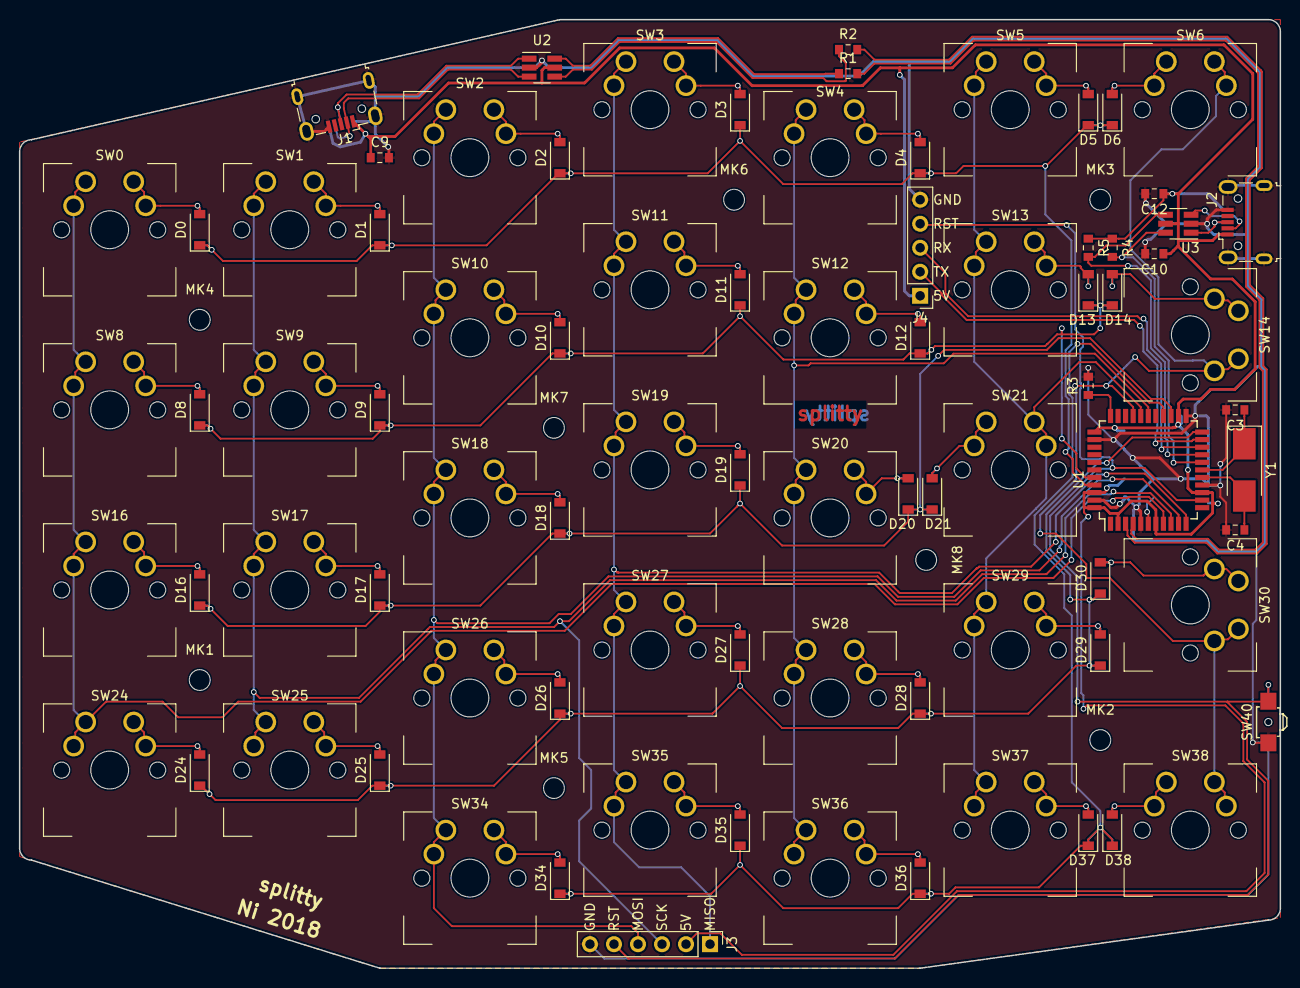
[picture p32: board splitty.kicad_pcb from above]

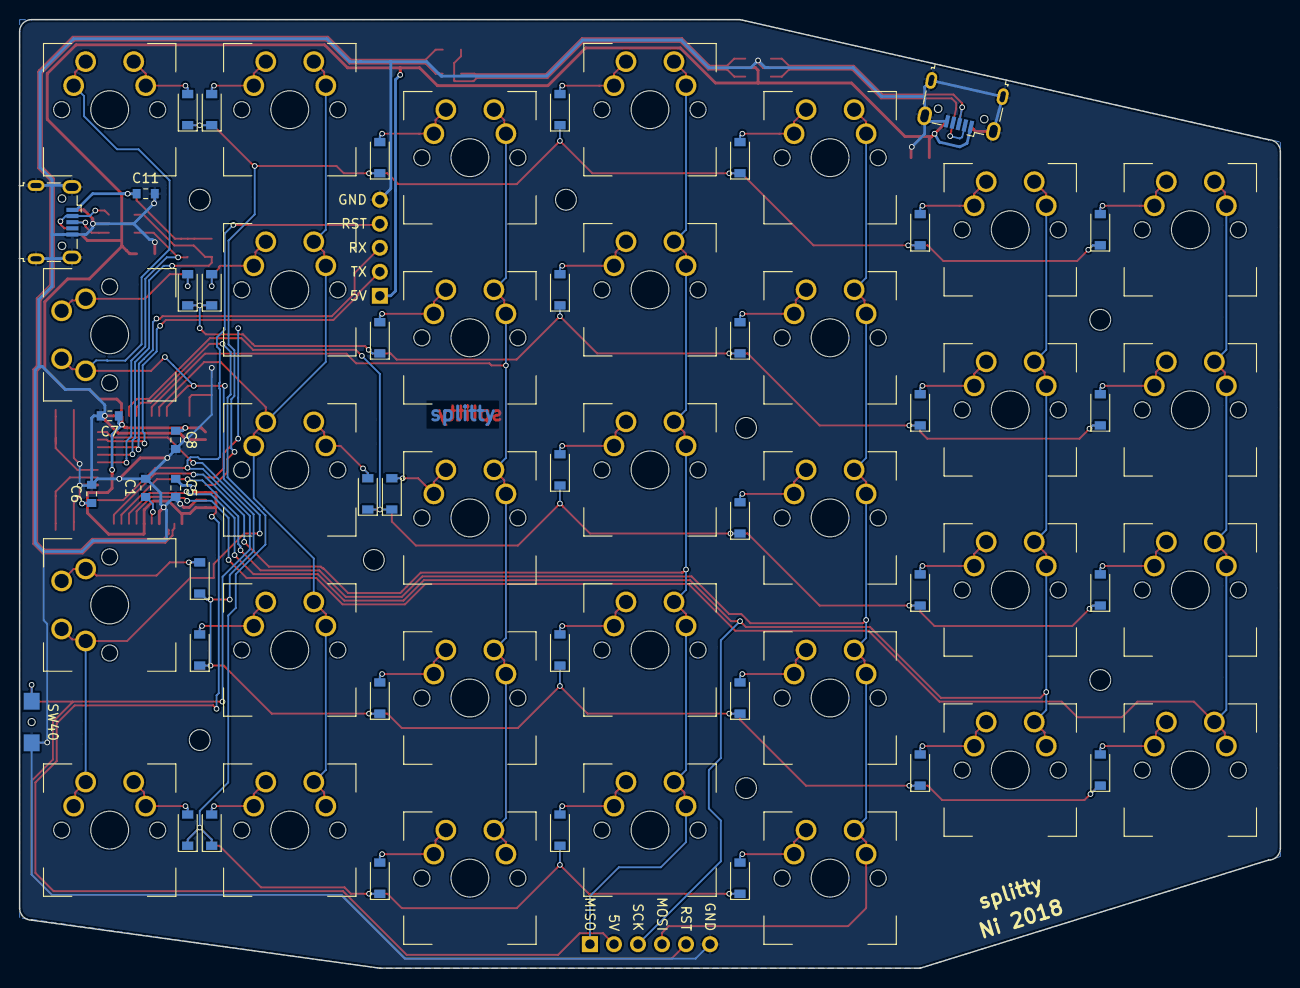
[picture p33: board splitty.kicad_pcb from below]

Board: 2 copper layers, 133.4 x 100.3 mm, 97 parts (6 on the bottom side), 63 nets.

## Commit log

2018-05-26 First release, full schematic and routed board
    [splitty.kicad_pcb, splitty.sch]
2018-05-26 Add front & back plates
    [splitty_back_plate.kicad_pcb, splitty_front_plate.kicad_pcb]
2018-05-27 Add drawing to backplate
    [splitty_back_plate.kicad_pcb]
2018-06-16 Update bom and README
2018-09-10 Update to Kicad 5
    [splitty.kicad_pcb, splitty.sch]
2020-01-09 BOM update
2021-02-07 Add more copyright and license info, upgrade Kicad
    [splitty.kicad_pcb, splitty.sch, splitty_back_plate.kicad_pcb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]
2021-02-07 Add schematic as PDF and fabrication files
    [splitty-B.Cu.gbr, splitty-B.Mask.gbr, splitty-B.Paste.gbr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]
